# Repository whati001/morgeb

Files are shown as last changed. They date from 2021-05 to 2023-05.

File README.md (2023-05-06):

# Morgeb - Unauthorized word-clock replica

**Morgeb** - the friendly word clock for every day's morning. This project should be a guideline for building your customized word clock. It contains the code and the manufacturing steps for my own version of the word clock, as shown below. The clock is 900x900 mm in size and weighs approximately 24 kg. The front is entirely rusted and looks terrific.

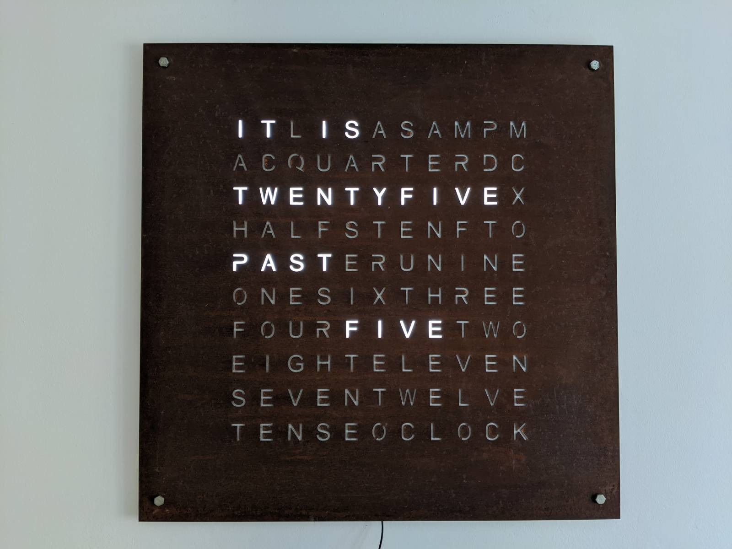
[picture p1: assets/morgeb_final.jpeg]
morgeb_front

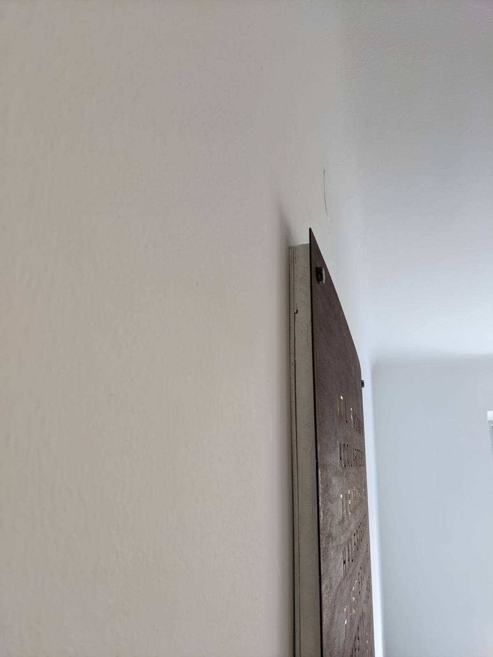
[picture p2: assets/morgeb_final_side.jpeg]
morgeb_side


The primary goal of this project was to design and manufacture a nice-looking word clock without the need for expensive equipment and with common tools. Additionally, it should be giant and straightforward to build. The current repository version only covers the English layout. However, porting to other languages should be straightforward and only requires reordering the characters and redefining their location in the C-Header file.

# Costs
| Name | Price |
| --- | --- |
| Frontpanel | 55 Euro  |
| Wood | 70 Euro  |
| Backplate  | 20 Euro  |
| LEDs | 150 Euro |
| Extra stuff| 10 Euro  |
| Mic | 25 Euro  |
| ---------- | -------- |
| Total | 330 Euro |

The clock cost me around 330 euros, which is not that cheap. But as we can see in the cost table, the LEDs cost the most, and this position can be easily reduced. As a spoiler, I have used eight controllable LEDs (NeoPixels) per character, which results in 880 LEDs in total. This amount is ridiculously high, and using half or just a quarter of them should be enough to achieve the same result.

# Manufacturing
Let's get started to step over each manufacturing step. The clock consists of the following four main parts, which we will now introduced:
* Front panel
* Wood body
* Backside
* Controller

## Front Panel
We have decided to make the front out of metal and let it rust. Therefore, we have designed the layout via the open source tool [Inkscape](https://inkscape.org/) and exported a [SVG](https://developer.mozilla.org/en-US/docs/Web/SVG) source, as well as the [DXF](https://www.autodesk.com/products/autocad/overview) file, stored inside the `frontpanel` directory. A friend of mine has access to a laser cutter machine, which accepts the DXF file. The final 900x900 mm metal plane is shown in the image below:
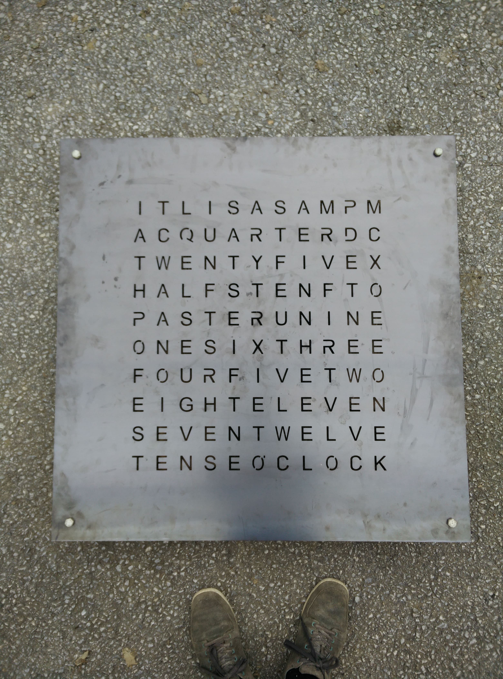
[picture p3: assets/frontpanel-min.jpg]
frontpanel


Because the plate weights approximately 12 kg, we placed four screws through the holds of the edges to secure the plate, instead of showing the minutes. If your clue, which mounts the panel to the later explained wood body, is strong enough, these screws should not be needed. I have used the [FixAll](https://www.soudal.de/diy/produkte/fix-all/fix-all/fix-all-high-tack#v12190) clue, which is for sure strong enough, but for safety reasons, the screws are there, and I think they give the clock a real badass touch. 

After laser cutting the metal, there is little to do. Rusting takes time; if you prefer, you can try one of these fast rust products. They have not worked for me, so I have waited one year until it was done. However, I have removed the cinder via a grinder before letting it rust.

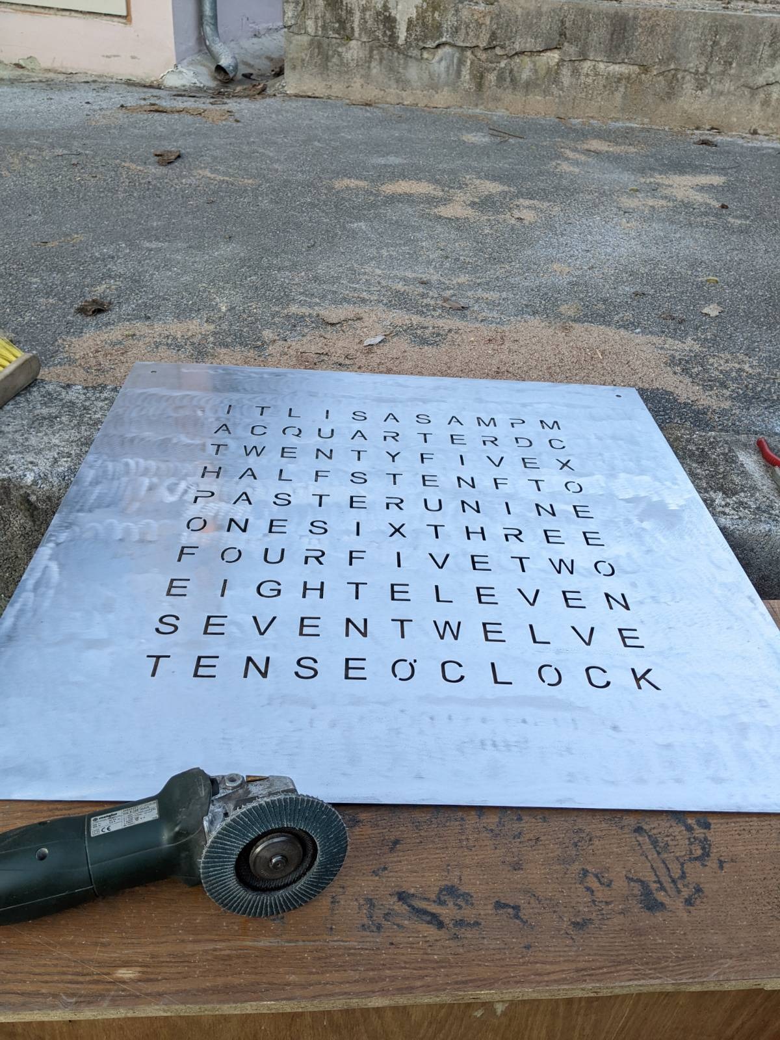
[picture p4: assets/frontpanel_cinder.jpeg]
frontpanel


Finally, I have clued strips of simple white bakery paper over the characters to defuse the light nicely. Unfortunately, the stips have not held as good as hoped. 

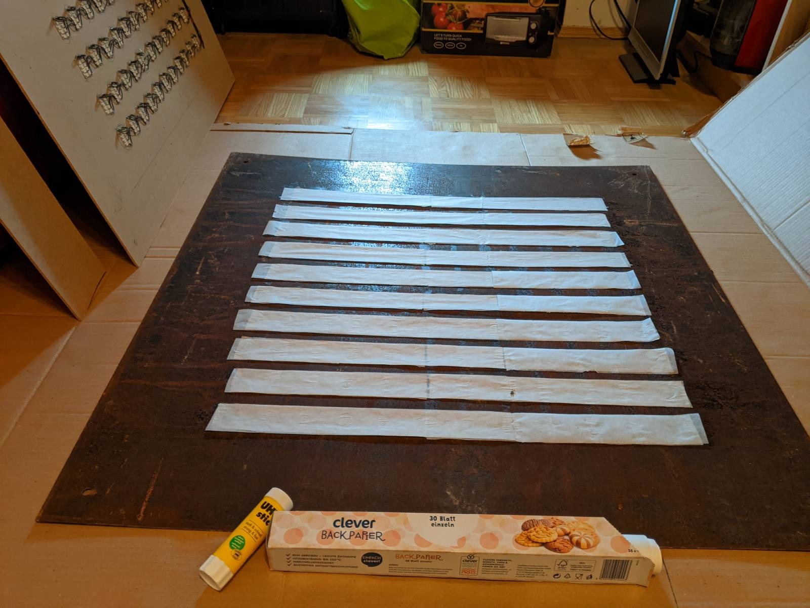
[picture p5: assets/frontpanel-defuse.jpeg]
frontpanel


Therefore, I used some hot glue after mounting the wood body to fix the bakery strips one more time.
I have used three layers of bakery paper to gain a lovely diffusion.

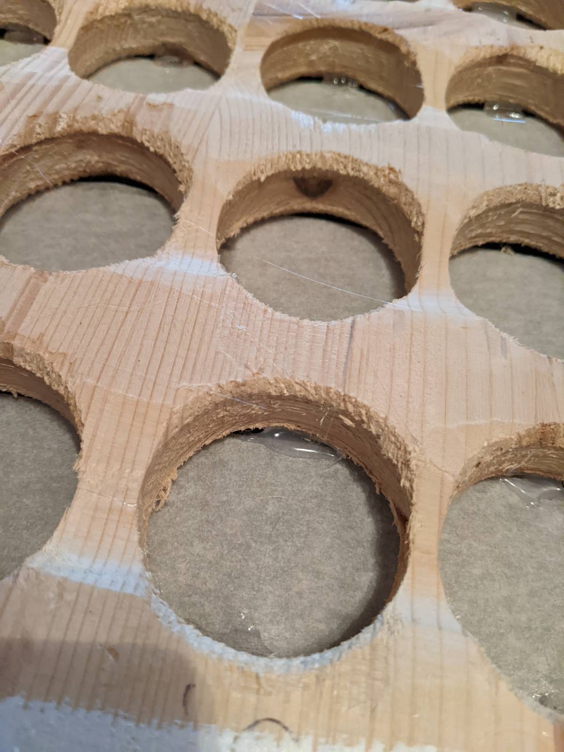
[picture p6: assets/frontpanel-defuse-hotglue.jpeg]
frontpanel


## Wood Body
The size of the wood body is a little bit smaller, approximately 888x888 mm, which gives the front panel some advance. The idea was to make the body invisible and let the front panel fly. Furthermore, the selected plate is a 27mm thick three-layer wood plate, which was available to me. But the decision was quite lucky because it is thick enough to achieve nice lighting and properly fix the front. 

Because the clock size was selected arbitrarily, and we had no idea how big the characters would be, there was no real guide on manufacturing the wood body. So, we started copying each character from the front panel to the wood and used try-and-error to find the perfect driller size. Finally, we picked a 45mm driller because the resulting hole was big enough to fit all characters and keep enough space between each hole for clueing the front panel. We used the `W` to measure if all symbols match because it is the biggest.
To perfectly center the 45 mm hole, we used a smaller driller in a preprocessing step to meet the middle later.

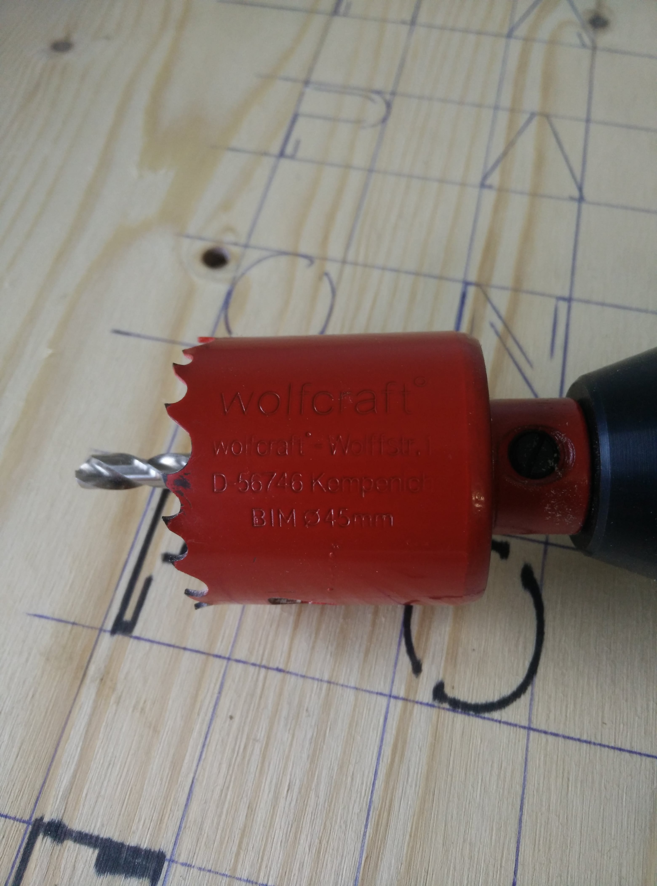
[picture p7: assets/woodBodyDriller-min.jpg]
woodBodyDriller

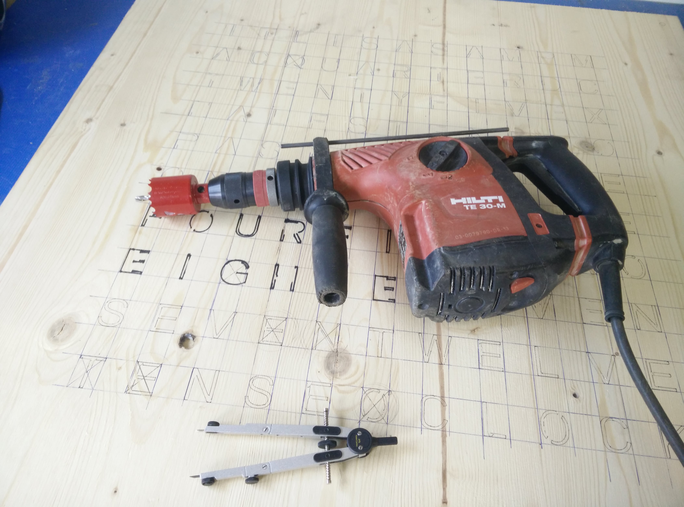
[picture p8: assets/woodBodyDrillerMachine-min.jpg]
woodBodyDrillerMachine

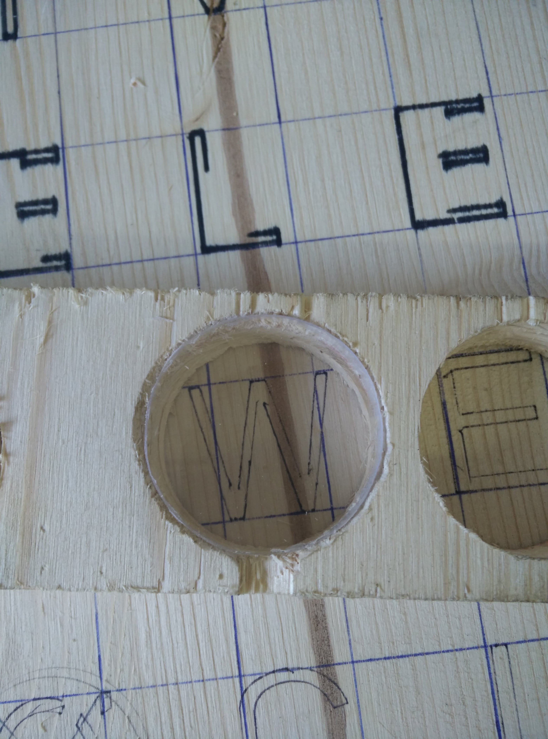
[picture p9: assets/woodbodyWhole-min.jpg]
woodBodyWhole

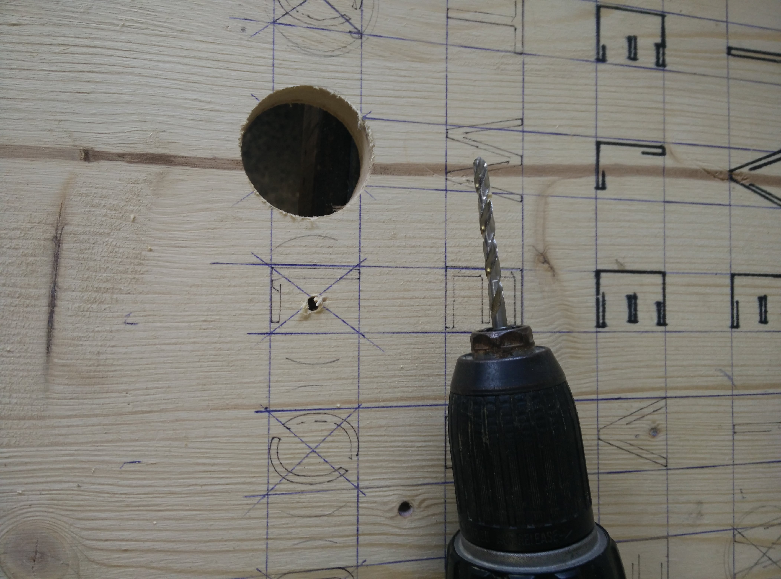
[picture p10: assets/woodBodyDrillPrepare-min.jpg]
woodBodyDrillPrepare

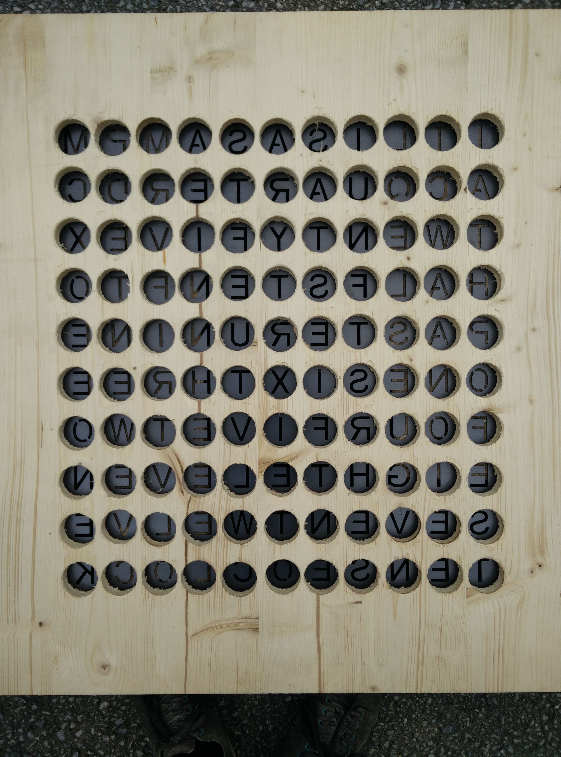
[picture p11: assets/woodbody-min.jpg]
woodBody


Finally, we smoothed the edges of each hole a bit. This process enlarges the hole size even more and prevents some edges of a character are not lighted up and remaining dark later. Additionally, we removed a little bit of wood between the holes in each horizontal lane. This path is later used by the cables connecting the LEDs from each character.
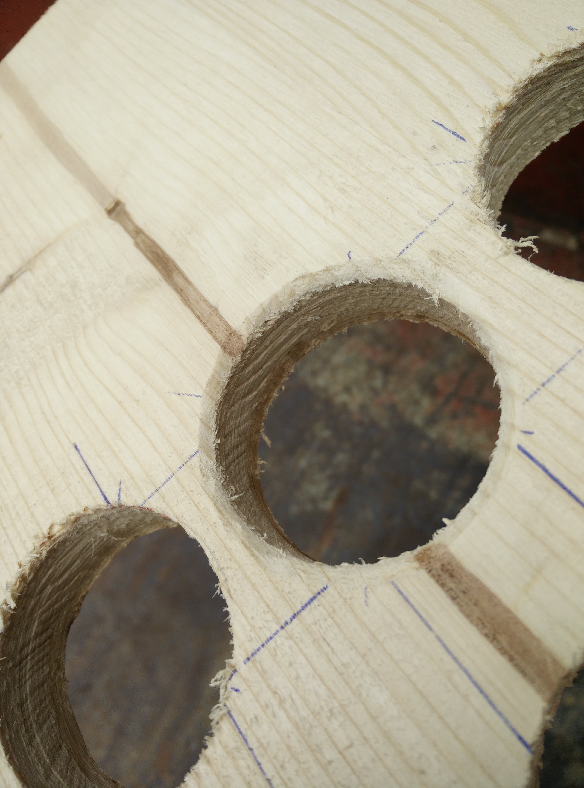
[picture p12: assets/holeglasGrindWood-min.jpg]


Next, we need to remove 2mm of wood at the top of the body. This allows us to integrate the metal strip with mounted/welded nuts into the wood body. In addition, we have cutted a strip on the right and left side, which will act as a mounting point. The idea is that the clock is held by the metal strip, which is screwed together with the front panel. Hence, there is no chance that the wood will break. We have used the angle grinder and a belt sander to remove the 2mm (metal thickness) from the wood plate. 

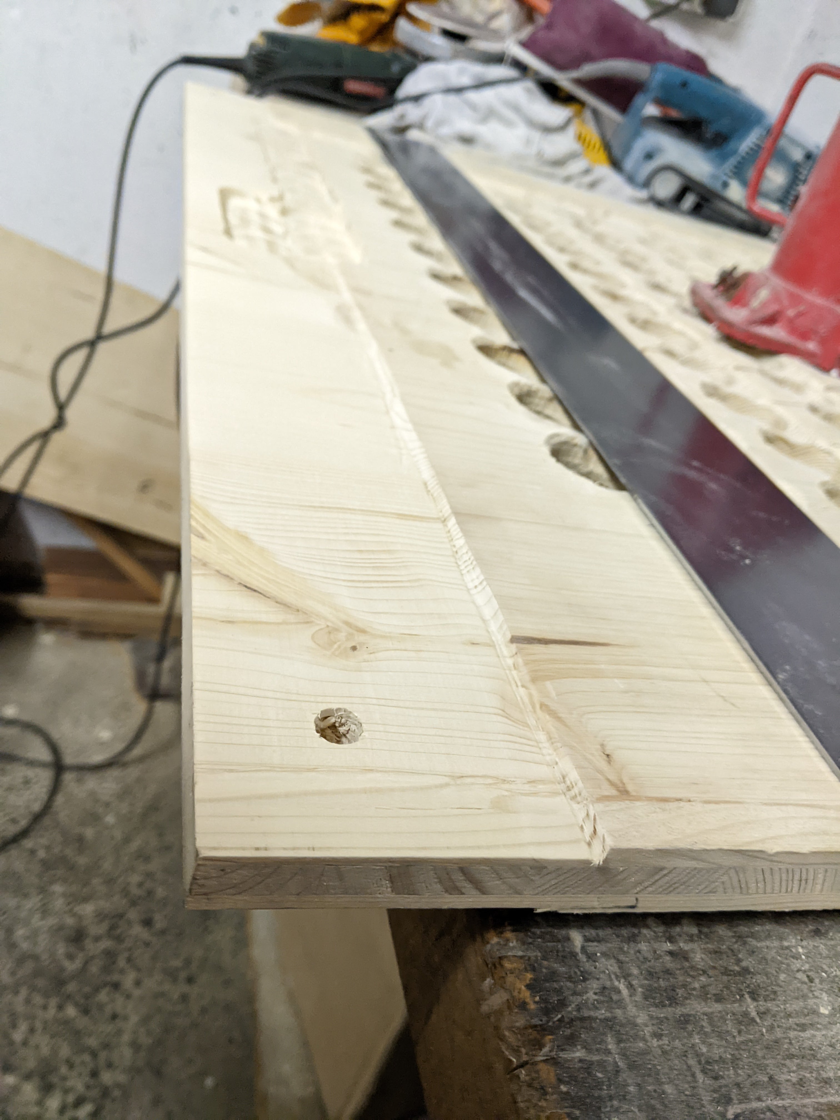
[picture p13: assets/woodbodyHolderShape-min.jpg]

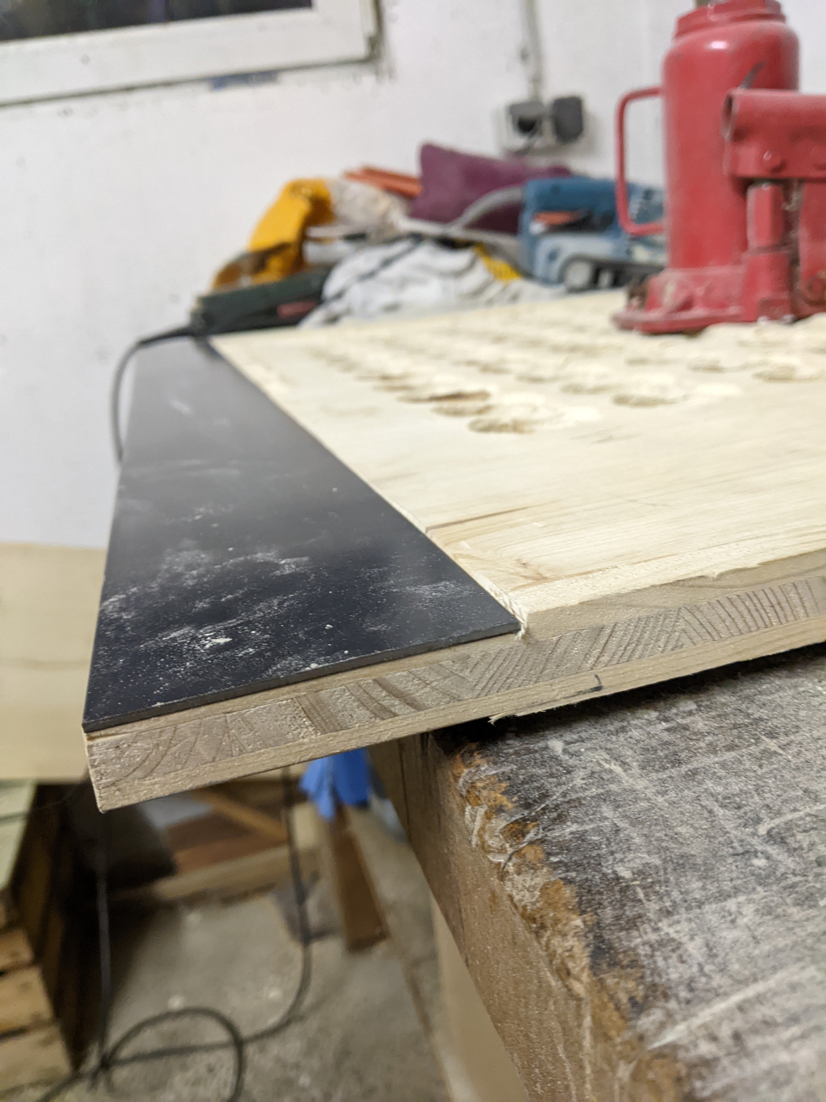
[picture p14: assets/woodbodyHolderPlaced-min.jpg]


Next, we need to cut out paths for the cables and the microcontroller. We used a 45mm driller and an angle grinder for this task. The result does not look very pretty, but nobody will see it. We simply drilled the first layer away, which indicated when we had to stop. However, this came with a small downside, small remaining pieces tend to break apart easily, so please be careful. Please apologize for the next image, that there is a path on the top. This was a mistake :)
Finally, we painted the body and we were done.

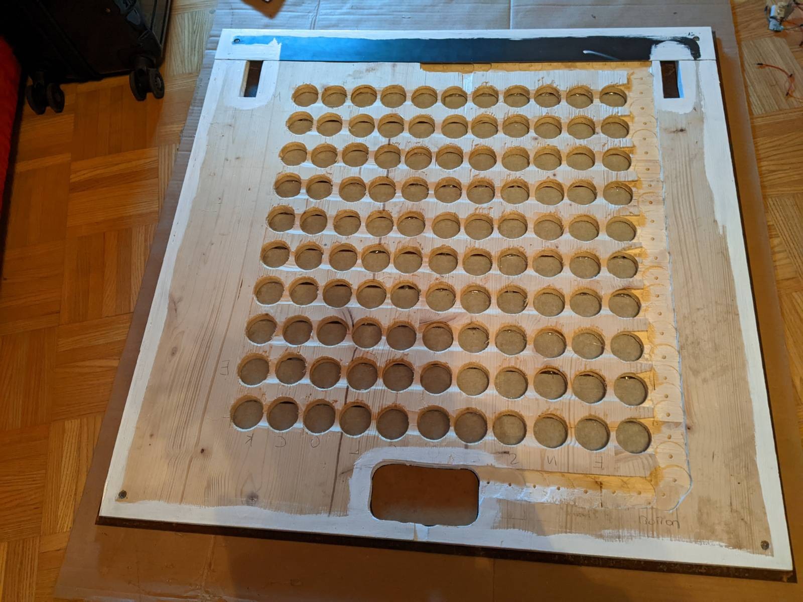
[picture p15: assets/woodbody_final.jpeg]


## Backside
Now, we will fabricate the backside with all the LEDs mounted. This part is the costliest one of the three ones because we need to do a lot of soldering. We have used a 4 mm press board with eight LEDs per character. Please feel free to use less than eight LEDs per character; it's a massive overkill. We have used 5050 SK6812 RGBW LEDs which are powered via 5V. 

Simply place the wood body on the pressboard and copy over the holes. After this, cut the LED strips and solder everything together.

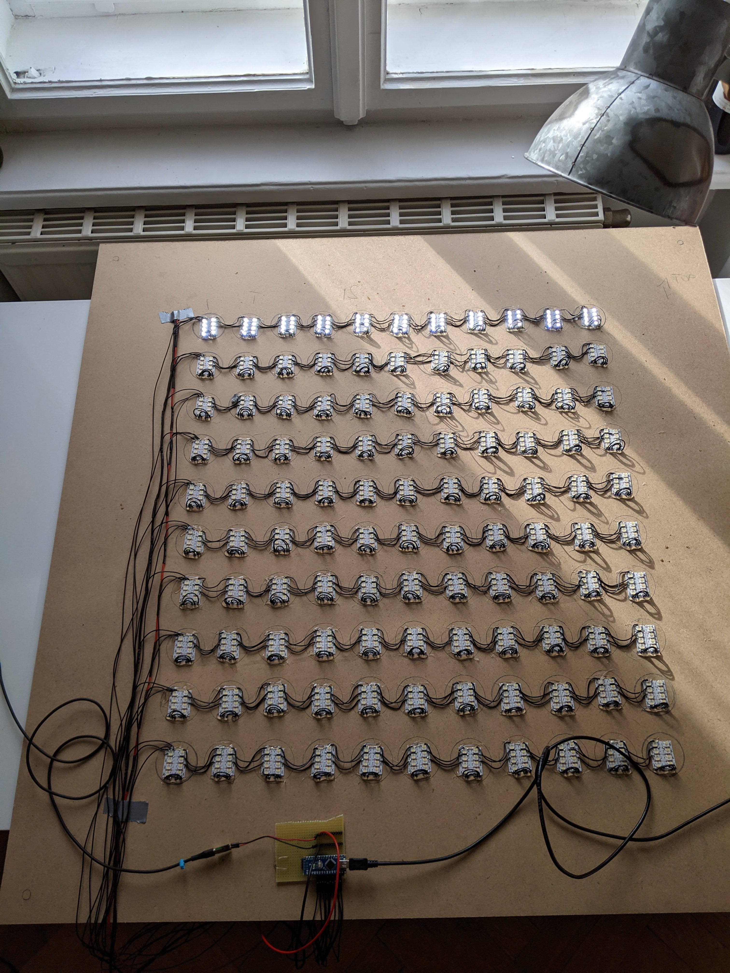
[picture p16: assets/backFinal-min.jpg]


Please ensure to use a big enough cable diameter that supports the current. We have chosen 0.125, which works but is the lower bound. After soldering everything, we fixed everything with hot glue.

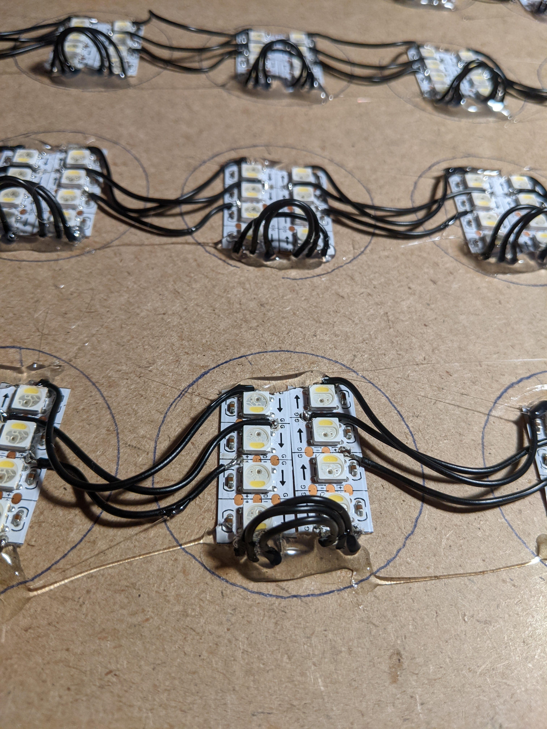
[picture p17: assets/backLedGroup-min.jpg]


To reduce the cables, we picked a 1.5mm cable for power and mass and soldered each line to it. In total, we ended up with ten control cables plus two for power. In total, twelve cables going to the controller.
Finally, we colored the pressboard also white and the back board is done. The plate is mounted to the wood body with simple screws.

## Controller
For the controller, we have picked an [AtMega382p](http://ww1.microchip.com/downloads/en/DeviceDoc/Atmel-7810-Automotive-Microcontrollers-ATmega328P_Datasheet.pdf) in combination with a [DS3231](https://datasheets.maximintegrated.com/en/ds/DS3231.pdf) RTC. The design is chosen so that it fits perfectly into the prepared hole. Additionally, added a photoresistor to adjust the LED brightness depending on the ambient light level. The resistor, together with the power cable, is exposed through a small cutout.

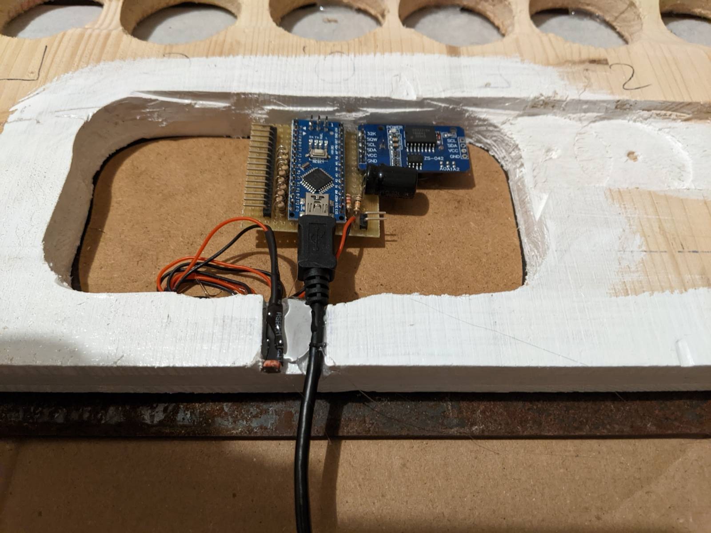
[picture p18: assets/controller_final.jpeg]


## Software
Please checkout the [code](./code) directory.

## Pictures
Because picture explain more than 1000 words, here some one from the final product.

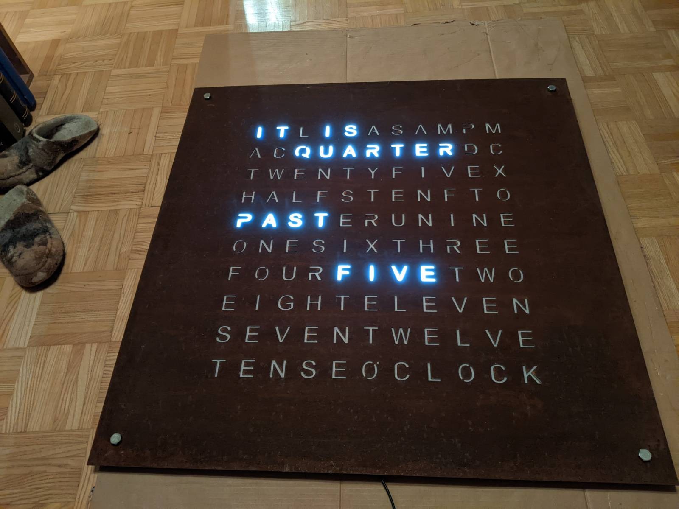
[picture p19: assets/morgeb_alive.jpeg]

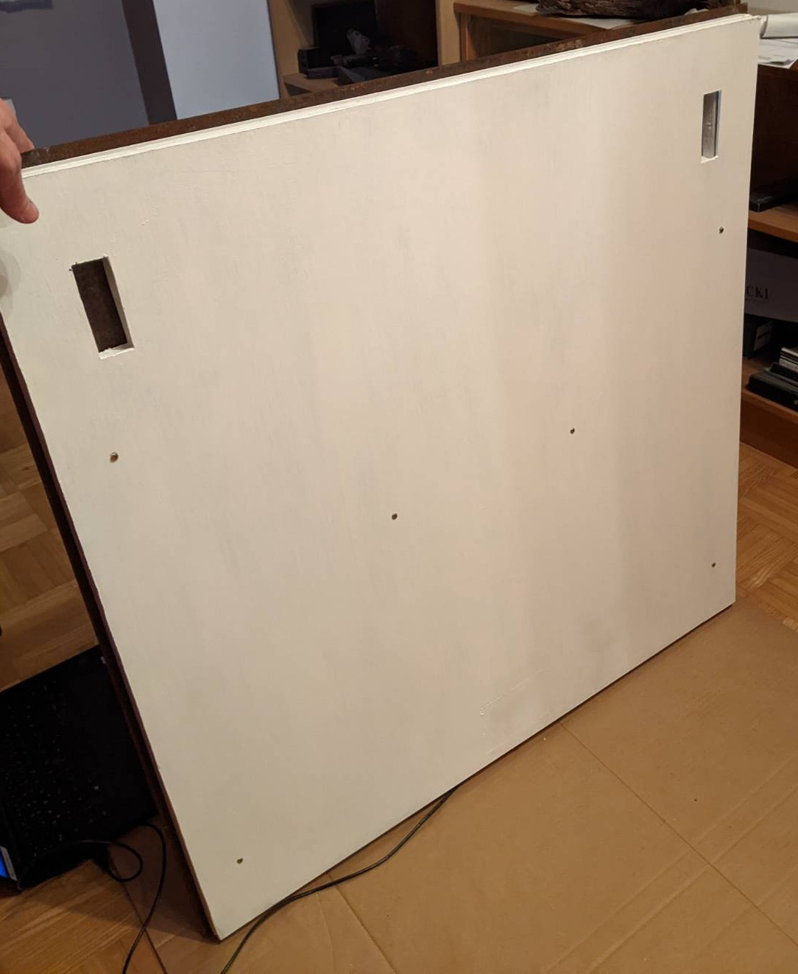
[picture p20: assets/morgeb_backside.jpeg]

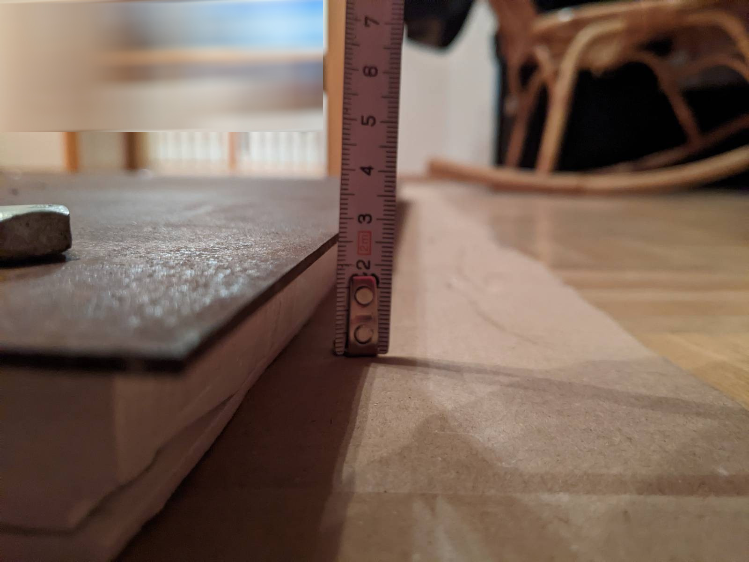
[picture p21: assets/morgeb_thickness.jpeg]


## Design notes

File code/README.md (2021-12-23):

# Morgeb Code

<p align="center">
  <p align="center">
    
    
    
  </p>
</p>
<br>

## About

This Project holds the source code for the project `Morgeb, the friendly clock for eachdays morning`.

## Software

The project is powered by an [AtMega382](http://ww1.microchip.com/downloads/en/DeviceDoc/Atmel-7810-Automotive-Microcontrollers-ATmega328P_Datasheet.pdf) in combination with a [DS3231](https://datasheets.maximintegrated.com/en/ds/DS3231.pdf) RTC.

### Used libraries
- [FrontPanel(private)](https://github.com/whati001/morgeb/tree/main/code/lib/frontpanel): FrontPanel wrapper lib
- [RTClib](https://github.com/adafruit/RTClib): Handle DS3231 RTC

### Code architecture

We have tried to keep the code as simple as possible.
So there is no wifi or similar available, it is a analog clock.

**!!! POC: Version !!!**

Currently, the code is still in POC, further we will add some buttons and brightness control.

During the setup phase, we initiate the RTC and FrontPanel.
Most of the time, the mc is sleeping, it get's woke up by the RTC every five minutes.
After wakeup, it fetches the current time and does the Frontpanel update.
```C++
void loop()
{
  DateTime now = rtc.now();
  // compute next wakeup, which is a multiple of 5 and has 0 seconds
  // hence, we substract the current seconds and compute the next smooth minute value
  DateTime nextWakeup = now -
                        TimeSpan(0, 0, now.minute(), now.second()) +
                        TimeSpan(0, 0, ((now.minute() + RTC_SLEEP_TIME) / RTC_SLEEP_TIME) * RTC_SLEEP_TIME, 0);
  rtc.setAlarm1(nextWakeup, DS3231_A1_Minute);

  frontpanel.update(now.hour(), now.minute(), now.second());

  // sleep until we need to update the clock again
  goSleep();
}
```

## ToDos:
Please find here all the open tasks, which are not needed by nice to have

* create an PCB for the driver
* properply find a nicer light diffusion way than milk folio

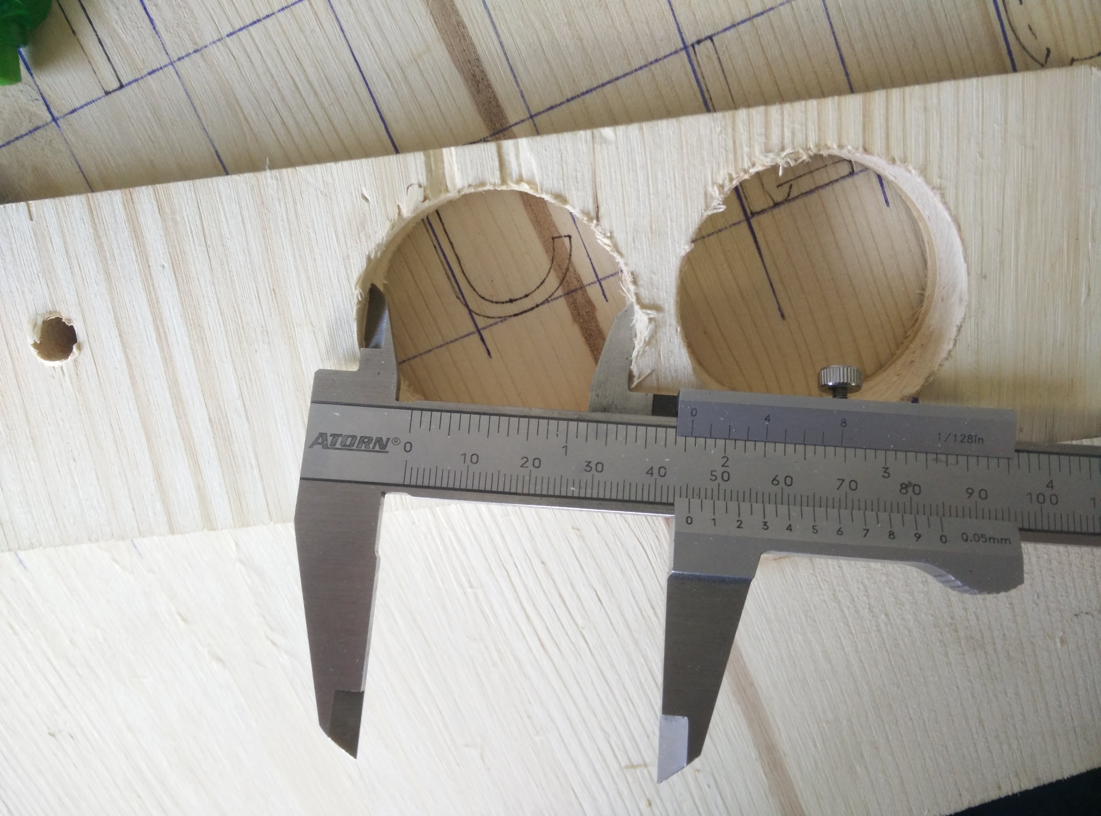
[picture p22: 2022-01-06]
assets/woodBodyFinalHole-min.jpg

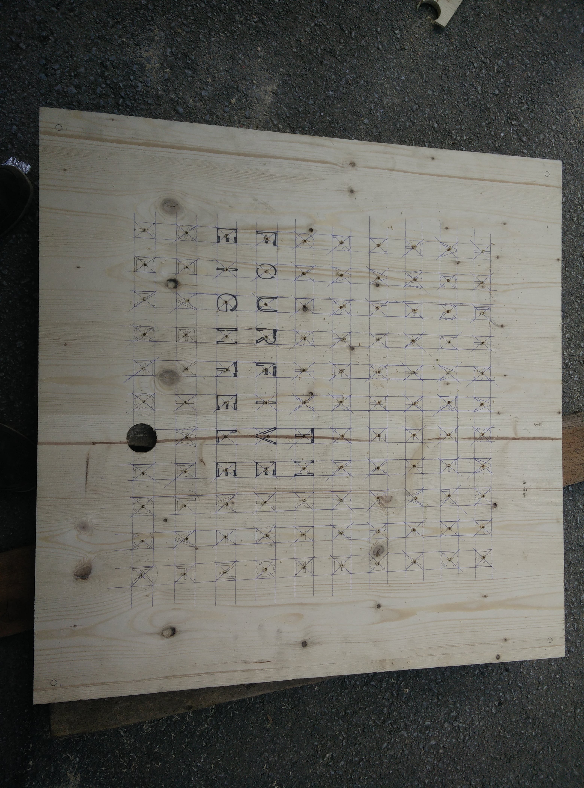
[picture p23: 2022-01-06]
assets/woodbodyCopy-min.jpg

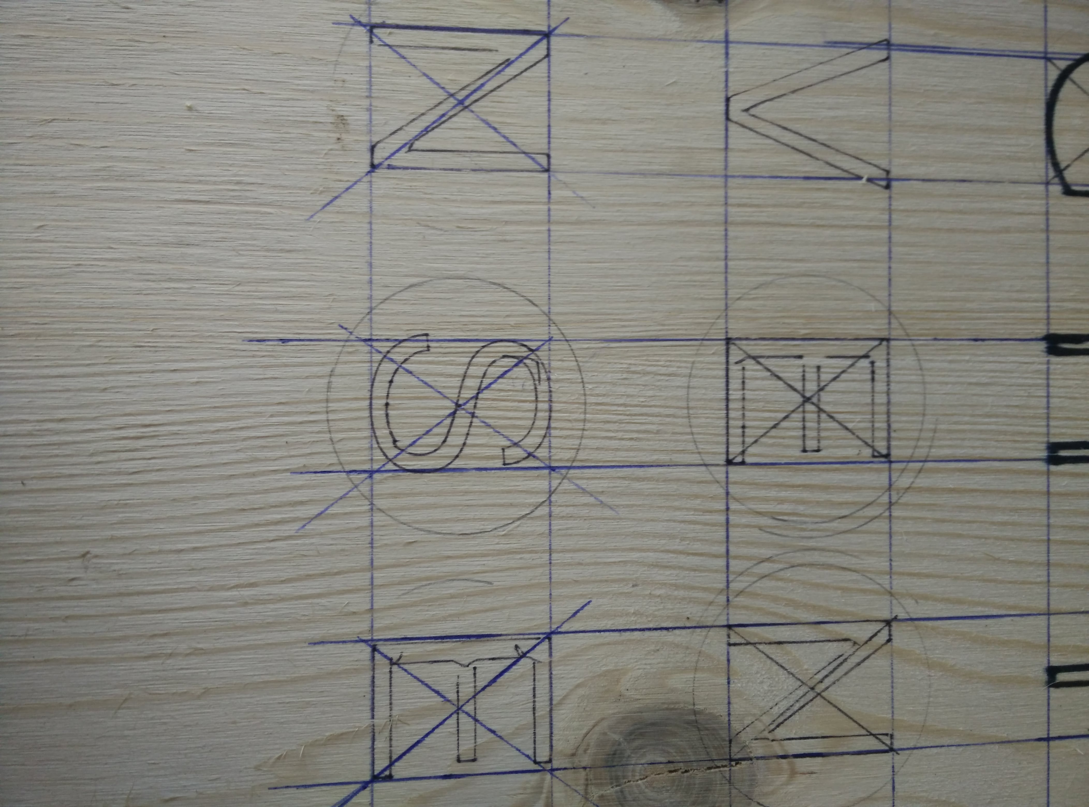
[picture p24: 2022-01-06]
assets/woodbodyMeasuring-min.jpg

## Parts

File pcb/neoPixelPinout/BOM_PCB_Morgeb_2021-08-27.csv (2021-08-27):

ID | Name | Designator | Footprint | Quantity | Manufacturer Part | Manufacturer | Supplier | Supplier Part | Price
1 | NeoPixel 2020 | N1,N2,N3,N4,N5 | NEOPIXEL 2020 | 5
2 | 5V | 5V1,5V2,DI2 | SOLDER_PAD | 3 | Solder Pad
3 | DI | DI1 | SOLDER_PAD | 1 | Solder Pad
4 | GND | GND1,GND2 | SOLDER_PAD | 2 | Solder Pad
5 | DO | DO1,DO2 | SOLDER_PAD | 2 | Solder Pad
6 | P1_DI | P1,P2,P3,P4,P5 | SOLDER_PAD | 5 | Solder Pad
7 | P1_DO | 1,2,3,4,5 | SOLDER_PAD | 5 | Solder Pad

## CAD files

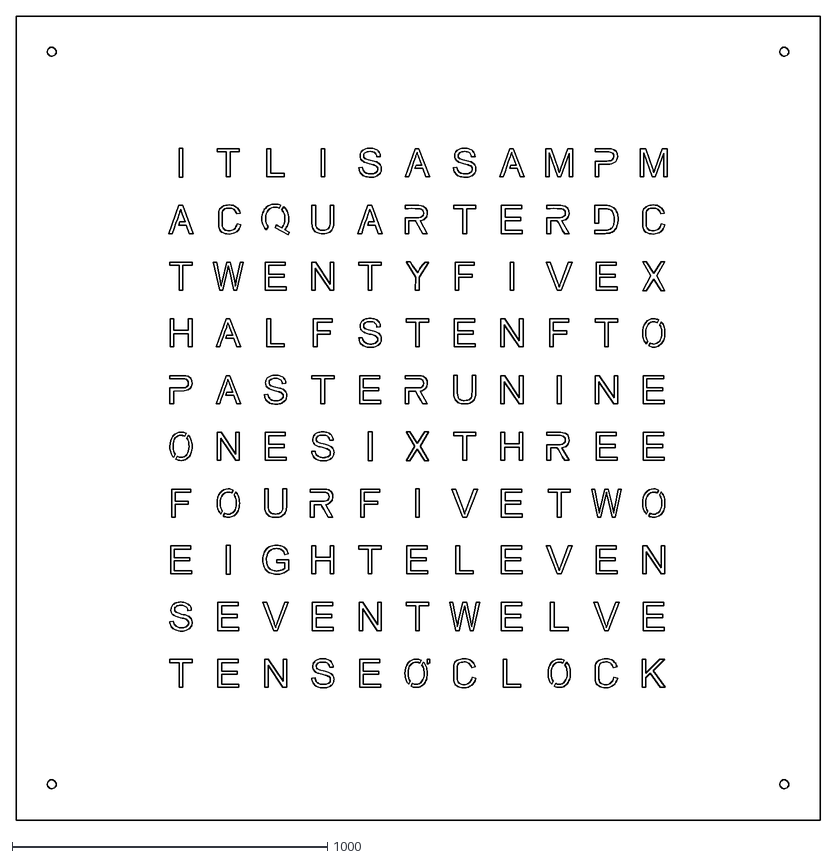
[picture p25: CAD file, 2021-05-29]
frontpanel/frontLayoutEN.dxf
2551.2 x 2551.2

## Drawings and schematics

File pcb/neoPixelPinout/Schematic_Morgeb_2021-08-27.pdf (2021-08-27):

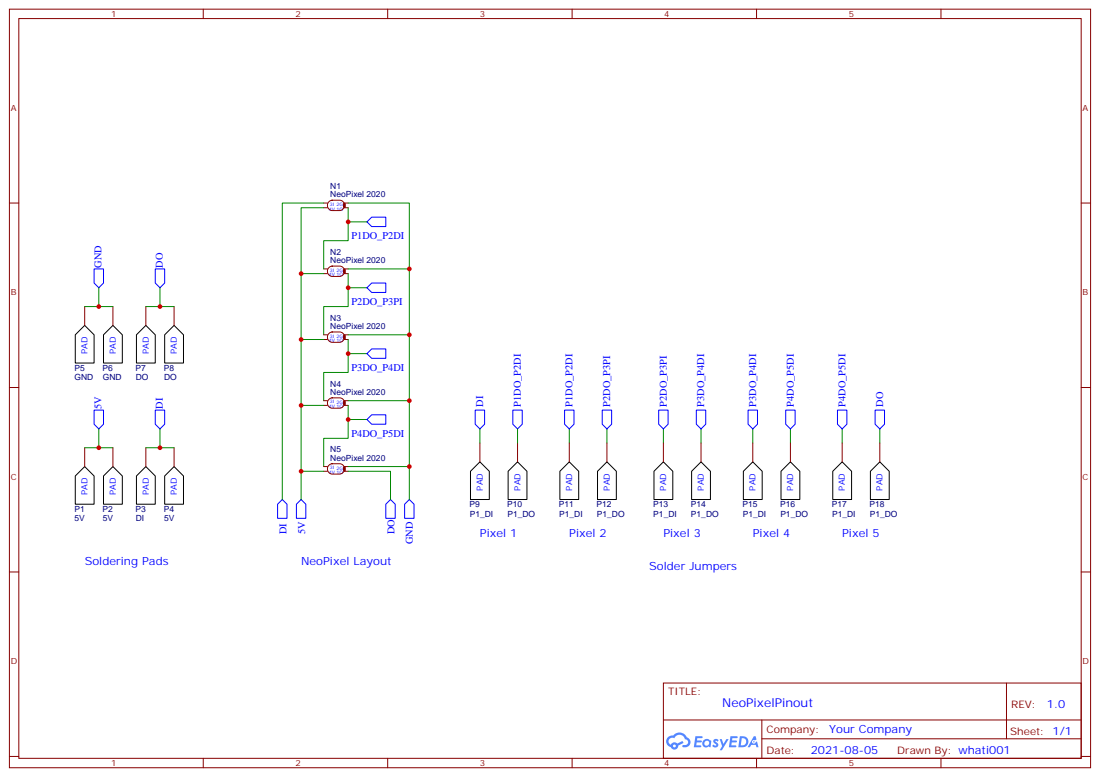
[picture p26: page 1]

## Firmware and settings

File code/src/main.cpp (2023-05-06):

#include <Arduino.h>
#include <SimpleSerialShell.h>
#include <avr/sleep.h>
#include <RTClib.h>
#include <EEPROM.h>

#include "morgeb.h"
#include "fp-sk6812.h"

uint8_t cshell_running;
RTC_DS3231 rtc;
SK6812FrontPanel_ frontpanel(LAYOUT_DIMENSION, LAYOUT, PIXEL_PER_CHAR);

/*
 * Small helper function to read persistent color value from EEPROM
 */
fp_color_ read_stored_color()
{
  uint8_t g = EEPROM.read(EEPROM_ADDR_COLOR_G);
  uint8_t b = EEPROM.read(EEPROM_ADDR_COLOR_B);
  uint8_t r = EEPROM.read(EEPROM_ADDR_COLOR_R);
  uint8_t w = EEPROM.read(EEPROM_ADDR_COLOR_W);
  return {g, r, b, w};
}

/*
 * Small helper function to store color value persistent on EEPROM
 */
void store_color(fp_color_ color)
{
  EEPROM.update(EEPROM_ADDR_COLOR_G, color.g);
  EEPROM.update(EEPROM_ADDR_COLOR_B, color.b);
  EEPROM.update(EEPROM_ADDR_COLOR_R, color.r);
  EEPROM.update(EEPROM_ADDR_COLOR_W, color.w);
}

/*
 * Small helper function to print time nicely
 */
void print_time(DateTime time)
{
  Serial.print("Time: ");
  Serial.print(time.hour());
  Serial.print(":");
  Serial.print(time.minute());
  Serial.print(".");
  Serial.println(time.second());
}
/*
 * Initiate the Real-Time-Clock (RTC)
 * This function will clear and disable both alarm instances
 */
int init_rtc()
{
  pinMode(RTC_WAKEUP_PIN, INPUT_PULLUP);

  if (false == rtc.begin())
  {
    return RET_ERROR_RTC;
  }
  if (rtc.lostPower())
  {
    Serial.println(F("RTC has lost power, let's reset the time to the compile time"));
    rtc.adjust(DateTime(F(__DATE__), F(__TIME__)));
  }

  rtc.disableAlarm(1);
  rtc.disableAlarm(2);
  rtc.clearAlarm(1);
  rtc.clearAlarm(2);

  rtc.writeSqwPinMode(DS3231_OFF);

  return RET_SUCCESS;
}

/*
 * Initiate Frontpanel library object
 */
int init_frontpanel()
{
  fp_color_ color = read_stored_color();
  Serial.print(F("Set frontpanel to "));
  SK6812FrontPanel_::print_color(color);

  frontpanel.init();
  frontpanel.update_color(color);
  // frontpanel.test_me();

  return RET_SUCCESS;
}

/*
 * Handel error message properly. If
 */
void handle_error(int err)
{
  switch (err)
  {
  case RET_SUCCESS:
    return; // avoid running into abort
  case RET_ERROR_RTC:
    Serial.println(F("RTC has lost power, let's reset the time to the compile time"));
    break;
  case RET_ERROR_FRONTPANEL:
    Serial.println(F("Failed to initialize the Frontpanel, please verify previous raised errors"));
    break;
  case RET_ERROR_SERIAL_CONSOLE:
    Serial.println(F("Failed to initialize the serial console, please verify previous raised errors"));
    break;
  default:
    Serial.print(F("Something unexpected occurred during the initialization, please read the code and investigate where the err-code: "));
    Serial.print(err);
    Serial.println(F(" comes from in the setup function"));
    break;
  }

  Serial.flush();
  abort();
}

/*
 * Initiate Morgeb application
 * This includes initiating the RTC, Frontpanel and Serial monitor
 */
int init_application()
{
  int err = RET_SUCCESS;
  Serial.begin(9600);
  while (!Serial)
    ;

  err = init_rtc();
  handle_error(err);
  Serial.println(F("Initiated Real-Time-Clock (RTC) properly"));

  err = init_frontpanel();
  handle_error(err);
  Serial.println(F("Initiated Frontpanel properly"));

  return err;
}

/*
 * Helper function to print help information for updateVar command
 */
void update_var_help()
{
  Serial.println(F("Incorrect amount of parameters passed to updateVar command."));
  Serial.println(F("Please pass the variable name and value, as shown below"));
  Serial.println(F("Available variables are: color(g r b w), time hh mm ss"));
  Serial.println(F("  > updateVar color 10 20 30 100"));
  Serial.println(F("  > updateVar time 14 45 48"));
}

/*
 * Serial console command to update variables
 */
int update_var(int argc, char **argv)
{
  Serial.println(F("## Update Morgeb-Clock variable"));
  Serial.println(argc);
  if (argc < 2)
  {
    update_var_help();
    return RET_ERROR_COMMAND;
  }

  char *varname = argv[1];
  if (strncmp(varname, "color", strlen("color")) == 0)
  {
    if (argc != 6)
    {
      update_var_help();
      return RET_ERROR_COMMAND;
    }

    // TODO: this is not save, we neither check for overflows during the conversion nor during the cast
    uint8_t g = atoi(argv[2]);
    uint8_t r = atoi(argv[3]);
    uint8_t b = atoi(argv[4]);
    uint8_t w = atoi(argv[5]);

    fp_color_ color = {g, r, b, w};
    store_color(color);

    frontpanel.update_color(color);
    Serial.print("Successfully updated color to: ");
    SK6812FrontPanel_::print_color(color);
  }
  else if (strncmp(varname, "time", strlen("time")) == 0)
  {
    if (argc != 5)
    {
      update_var_help();
      return RET_ERROR_COMMAND;
    }

    // TODO: this is not save, we neither check for overflows during the conversion nor during the cast
    uint8_t h = atoi(argv[2]);
    uint8_t m = atoi(argv[3]);
    uint8_t s = atoi(argv[4]);

    // year, month, day does not matter, so let's use dummy value
    DateTime time = DateTime(2022, 01, 01, h, m, s);
    rtc.adjust(time);

    Serial.print("Successfully updated time to: ");
    print_time(time);
  }
  else
  {
    update_var_help();
    return RET_ERROR_COMMAND;
  }

  return RET_SUCCESS;
}

/*
 * Serial console command to print all variables
 */
int print_vars(int argc, char **argv)
{
  Serial.println(F("## Print Morgeb-Clock variables"));
  fp_color_ color = read_stored_color();
  Serial.print(F("  * "));
  SK6812FrontPanel_::print_color(color);
  Serial.print(F("  * "));
  print_time(rtc.now());

  return RET_SUCCESS;
}

int exit(int argc, char **argv)
{
  Serial.println(F("## Exit configuration shell"));
  cshell_running = 0;
  return RET_SUCCESS;
}

void flush_serial_input()
{
  while (Serial.available() > 0)
  {
    Serial.read();
  }
}

int config_shell_requests()
{
  uint32_t timeout = 0;
  while (timeout < USER_CONFIG_MS_TIMEOUT)
  {
    if (Serial.available())
    {
      if (' ' == Serial.read())
      {
        return 1;
      }
      flush_serial_input();
    }
    delay(USER_CONFIG_POLL_MS_TIMEOUT);
    timeout += USER_CONFIG_POLL_MS_TIMEOUT;
  }
  return 0;
}

/*
 * Handler to allow the user to adjust clock specific variables
 * like the color and so forth
 */
int handle_user_interaction()
{
  Serial.println(F("Welcome to the Serial output of the Morgeb-Clock"));
  Serial.println(F("User configuration phase started, this allows you to persistently change values of the clock"));
  Serial.print(F("If no SPACE key is read for "));
  Serial.print(USER_CONFIG_SEC_TIMEOUT);
  Serial.println(F(" seconds, the clock will start"));
  Serial.println(F("Please press SPACE to start configuration shell"));
  Serial.flush();

  cshell_running = config_shell_requests();
  if (cshell_running)
  {
    shell.attach(Serial);
    shell.addCommand(F("updateVar <update variable value>..."), update_var);
    shell.addCommand(F("printVars <print all variable values>..."), print_vars);
    shell.addCommand(F("exit <exit configuration shell>..."), exit);
    shell.printHelp(0, NULL);
    Serial.print(F("> "));

    while (1 == cshell_running)
    {
      shell.executeIfInput();
    }
  }

  return RET_SUCCESS;
}

/*
 * Setup all cock components and provide
 * the user to configure the clock accordantly
 */
void setup()
{
  int err = init_application();
  handle_error(err);
  Serial.println(F("Initiated Morgeb-Clock components properly"));

  err = handle_user_interaction();
  handle_error(err);
  Serial.println(F("Setup phase done, clock will start showing the time"));

  Serial.flush();
}

/*
 * ISR called when the RTC injects an external interrupt
 */
void wakeupISR()
{
  Serial.println("Some interrupt occrued");
  sleep_disable();
  detachInterrupt(digitalPinToInterrupt(RTC_WAKEUP_PIN));
}

/*
 * Send the mic to POWER DOWN mode to save energy
 * He will be woken up by external interrupts, triggered by the RTC on D2 (nano)
 */
void goSleep()
{
  sleep_enable();
  set_sleep_mode(SLEEP_MODE_PWR_DOWN);

  noInterrupts();
  attachInterrupt(digitalPinToInterrupt(RTC_WAKEUP_PIN), wakeupISR, LOW);

  interrupts();
  Serial.flush();
  sleep_cpu();

  //---------------------------------------------------------------------------
  /* The program will continue from here when it wakes */
  //---------------------------------------------------------------------------

  rtc.disableAlarm(1);
  rtc.clearAlarm(1);
}

/*
 * Update the time every five minutes
 * Let the microcontroller sleep with in the Power Down mode to save energy
 */
void loop()
{
  // compute next wakeup, which is a multiple of 5 and has 0 seconds
  // hence, we substract the current seconds and compute the next smooth minute value
  DateTime now = rtc.now();
  DateTime next_wakeup = now -
                         TimeSpan(0, 0, now.minute(), now.second()) +
                         TimeSpan(0, 0, ((now.minute() + RTC_SLEEP_TIME) / RTC_SLEEP_TIME) * RTC_SLEEP_TIME, 0);
  if (false == rtc.setAlarm1(next_wakeup, DS3231_A1_Minute))
  {
    Serial.println("Failed to set wakeup alarm, microcontroller maybe starve now");
  }

  Serial.print(F("Microcontroller will sleep until "));
  print_time(next_wakeup);

  // #TODO: find a better logic
  DateTime now_five_base = now -
                           TimeSpan(0, 0, now.minute(), now.second()) +
                           TimeSpan(0, 0, ((now.minute()) / RTC_SLEEP_TIME) * RTC_SLEEP_TIME, 0);

  frontpanel.update(now_five_base.hour(), now_five_base.minute(), now_five_base.second());

  goSleep();
}

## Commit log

2021-05-29 AK - added vector for front
    [frontLayoutEN.dxf]
2021-08-26 AK - fixed but with sleep time
    [main.cpp]
2021-08-27 AK - added housing doc
    [frontLayoutEN.dxf]
2021-08-27 AK - added Hardware info
    [BOM_PCB_Morgeb_2021-08-27.csv]
2021-11-04 AK - updated to use ArduinoNano
2022-09-20 Added serial console to update color and time without flashing the device (#2)
    * AK - added simple serial console skeleton
    * AK - finalized the serial console code and added functionality to update the color
    * AK - added stuff for nano
    * AK - prettified code a bit
    * AK - added functionality to set time
2022-12-22 AK - fixed some small bugs
    [main.cpp]
2023-05-06 AK - fixed bug and optimized user input handling
    [main.cpp]

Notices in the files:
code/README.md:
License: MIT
